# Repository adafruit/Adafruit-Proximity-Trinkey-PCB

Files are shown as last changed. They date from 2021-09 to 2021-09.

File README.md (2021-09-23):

## Adafruit Proximity Trinkey PCB

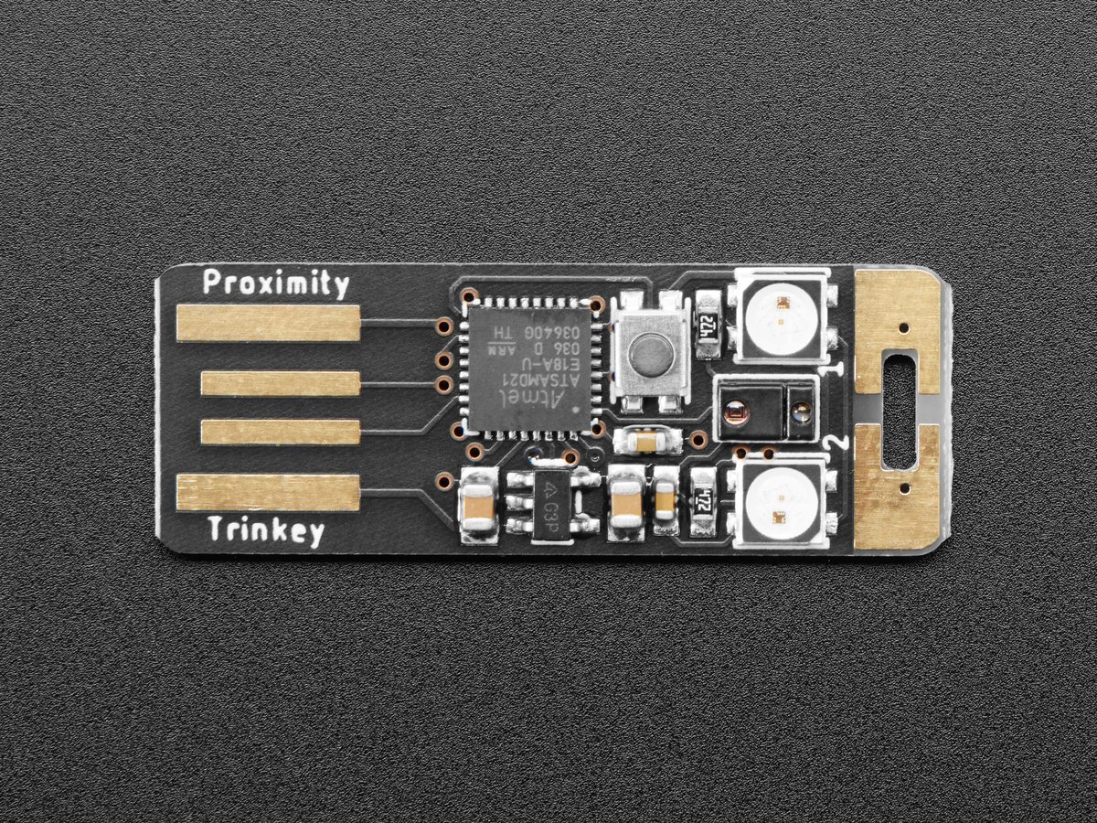
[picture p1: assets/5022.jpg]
<a href="http://www.adafruit.com/products/5022"><br/>
Click here to purchase one from the Adafruit shop</a>

PCB files for the Adafruit Proximity Trinkey. 

Format is EagleCAD schematic and board layout
* https://www.adafruit.com/product/5022

### Description

It's half USB Key, half Adafruit Trinket M0, half APDS9960 breakout...it's Proximity Trinkey, the circuit board with a Trinket M0 heart, APDS9960 Proximity, Light, RGB, and Gesture Sensor, and two RGB NeoPixels for a customizable glow. We wanted to make it super-easy to add one of our most popular combination-sensors to any computer with a USB port and this one is ready to go in an instant.

The PCB is designed to slip into any USB A port on a computer or laptop. There's an ATSAMD21 microcontroller on board with just enough circuitry to keep it happy. One pin of the microcontroller connects to the two NeoPixel LEDs. Two other pins are used as capacitive touch inputs on the end - if you look carefully you can see the slotted end has left and right touch pads. A reset button lets you enter bootloader mode if necessary. That's it!

The SAMD21 can run CircuitPython or Arduino very nicely - both have existing APDS9960, NeoPixel and our FreeTouch (capacitive touch) libraries. Over the USB connection, you can have serial, MIDI, or HID connectivity. The Proximity Trinkey is perfect for simple projects that want to use motion, light or color sensing as an input to make fun and intuitive user experiences.

The star of this Trinkey is the APDS9960 from Avago Technologies, which has a few different capabilities thanks to integrated IR LED, photodiodes, and RGB sensing:

* Proximity sensing up to about 6" away by bouncing IR light off an object
* RGB color sensing can detect color when light refects off of an object - good for bright colorful items like LEGO bricks
* Ambient light sensing - how dark or bright is it in the room?
* Basic gesture sensing using 4 cardinal locations of photodiodes - this sensor is a little tough to use but it does work with practice
* Configurable interrupt pin that can fire when a certain proximity threshold is broken, or when a color sensor breaks a certain threshold.

We think it's just an adorable little board, small and durable and inexpensive enough that it could be a first microcontroller board or inspiration for advanced developers to make something simple and fun.

* ATSAMD21E18 32-bit Cortex M0+ - 48 MHz 32 bit processor with 256KB Flash and 32 KB RAM
* Native USB supported by every OS - can be used in Arduino or CircuitPython as USB serial console, MIDI, Keyboard/Mouse HID, even a little disk drive for storing Python scripts.
* Can be used with Arduino IDE or CircuitPython
* Two RGB NeoPixel LEDs
* Two Capacitive Touchpads
* APDS9960 Light/Color/Proximity/Gesture sensor
* Reset switch for starting your project code over or entering bootloader mode
* Slim and cute, keychain-friendly!

### License

Adafruit invests time and resources providing this open source design, please support Adafruit and open-source hardware by purchasing products from [Adafruit](https://www.adafruit.com)!

Designed by Limor Fried/Ladyada for Adafruit Industries.

Creative Commons Attribution/Share-Alike, all text above must be included in any redistribution. 
See license.txt for additional details.

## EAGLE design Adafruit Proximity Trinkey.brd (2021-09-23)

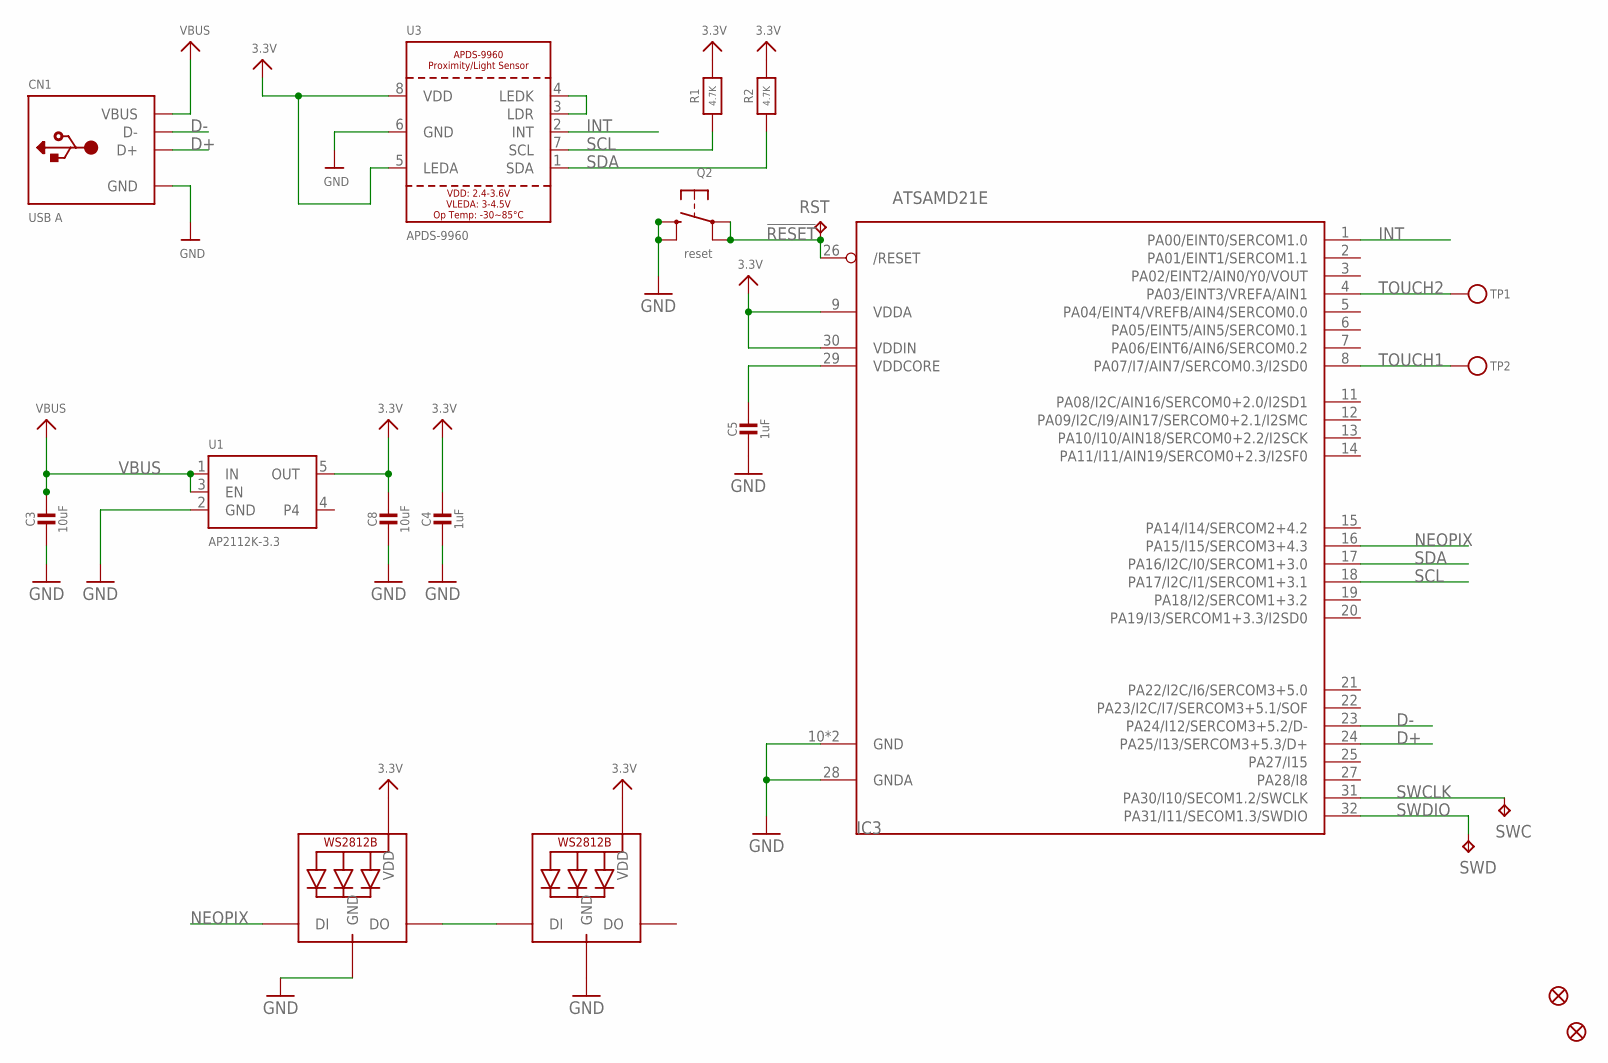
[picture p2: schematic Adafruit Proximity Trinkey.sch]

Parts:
C3, C8: 10uF; 0805-NO
C4, C5: 1uF; 0603-NO
CN1: USB A; USBA_PCB
FID1, FID2: FIDUCIAL_1MM
IC3: ATSAMD21E; QFN32_5MM
LED1, LED2: WS2812B3535; LED3535
Q2: reset; BTN_KMR2_4.6X2.8
R1, R2: 4.7K; 0603-NO
RST: TPTP16R; TP16R
SWC: TPTP15R; TP15R
SWD: TPTP16R; TP16R
TP1, TP2: TESTPOINTROUND1.5MMNO; TESTPOINT_ROUND_1.5MM_NO
U1: AP2112K-3.3; SOT23-5
U3: APDS-9960

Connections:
3.3V: C4.1, C8.1, IC3.9 (VDDA), IC3.30 (VDDIN), LED1.2 (VDD), LED2.2 (VDD), R1.2, R2.2, U1.5 (OUT), U3.5 (LEDA), U3.8 (VDD)
!RESET: IC3.26 (/RESET), Q2.A, Q2.A' (P1), RST.TP
D+: CN1.USB_PLUS (D+), IC3.24 (PA25/I13/SERCOM3+5.3/D+)
D-: CN1.USB_NEG (D-), IC3.23 (PA24/I12/SERCOM3+5.2/D-)
GND: C3.2, C4.2, C5.2, C8.2, CN1.GND, IC3.10 (GND), IC3.28 (GNDA), IC3.33 (GND), LED1.4 (GND), LED2.4 (GND), Q2.B (S), Q2.B' (S1), U1.2 (GND), U3.6 (GND)
INT: IC3.1 (PA00/EINT0/SERCOM1.0), U3.2 (INT)
unnamed: LED1.1 (DI), LED2.3 (DO)
unnamed: U3.3 (LDR), U3.4 (LEDK)
NEOPIX: IC3.16 (PA15/I15/SERCOM3+4.3), LED2.1 (DI)
SCL: IC3.18 (PA17/I2C/I1/SERCOM1+3.1), R1.1, U3.7 (SCL)
SDA: IC3.17 (PA16/I2C/I0/SERCOM1+3.0), R2.1, U3.1 (SDA)
SWCLK: IC3.31 (PA30/I10/SECOM1.2/SWCLK), SWC.TP
SWDIO: IC3.32 (PA31/I11/SECOM1.3/SWDIO), SWD.TP
TOUCH1: IC3.8 (PA07/I7/AIN7/SERCOM0.3/I2SD0), TP2.P$1
TOUCH2: IC3.4 (PA03/EINT3/VREFA/AIN1), TP1.P$1
VBUS: C3.1, CN1.VCC (VBUS), U1.1 (IN), U1.3 (EN)
VDDCORE1: C5.1, IC3.29 (VDDCORE)

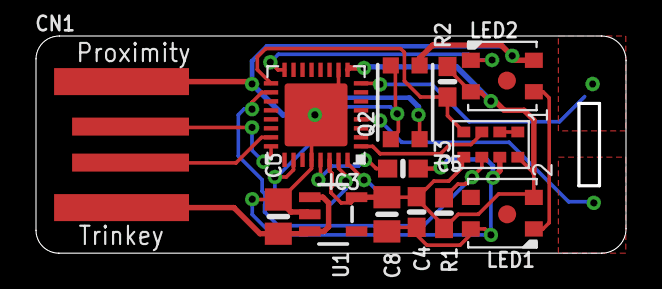
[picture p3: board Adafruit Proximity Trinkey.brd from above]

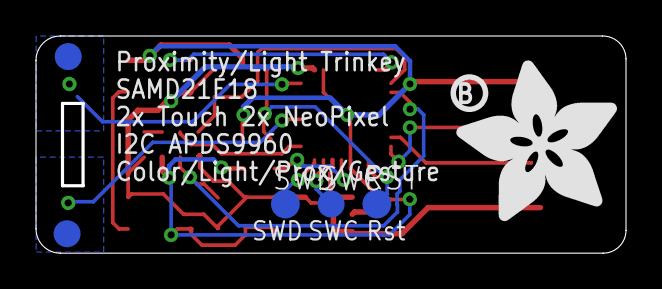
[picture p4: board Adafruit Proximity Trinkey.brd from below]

Board: 2 copper layers, 32.8 x 12.1 mm, 22 parts (7 on the bottom side), 17 nets.

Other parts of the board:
U$8: PCBFEAT-REV-040
U$10: ADAFRUIT_9MM

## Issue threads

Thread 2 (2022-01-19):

the board doesn't show up in bootloader mode

mr-nobody20, 2022-01-19:
Hello, its my first time using trinkies and im having a problem with the proximity trinkey when i plug it in, normally it activates the light sensors but when i try to plug it in pressing the bootloader button it just don't show up on my computer so if someone can provide a little help about how can i get to the bootloader mode that will be great

my machine is linux but tried it on windows vm too still doesn't show up

ladyada, 2022-01-19:
hiya, questions about how to use adafruit products are best posted in the adafruit forums  at [forums.adafruit.com](forums.adafruit.com/)
thats where tech support is handled - github issues are where folks can issue bug reports (e.g. something that ought to work but doesnt due to a hardware or software bug)

thanks! :)

Closed 2022-01-19.

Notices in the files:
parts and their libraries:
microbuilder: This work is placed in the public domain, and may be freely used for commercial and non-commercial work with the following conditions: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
